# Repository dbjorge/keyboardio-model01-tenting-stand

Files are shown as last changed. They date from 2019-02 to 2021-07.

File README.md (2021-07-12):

# keyboardio-model01-tenting-stand

The 3D model for the tenting stand I use with my [Keyboardio Model 01](https://keyboard.io) keyboard.

**WARNING: To avoid wear on your keyboard, you MUST use some sort of pad/bumper between the stand/keyboard and your desk!** Using these models, part of the weight of the keyboard rests on one of its wooden edges; this is by design, as it forces a consistent angle between the stand and keyboard. However, you risk chipping the contact point on the keyboard unless you put some sort of padding there! I found that some felt stick-on furniture pads I had lying around worked well for this (I'm using [these SoftTouch brand ones](https://www.amazon.com/dp/B000SL4GEM/ref=cm_sw_em_r_mt_dp_U_9tJCCbQ0N5YCF)).

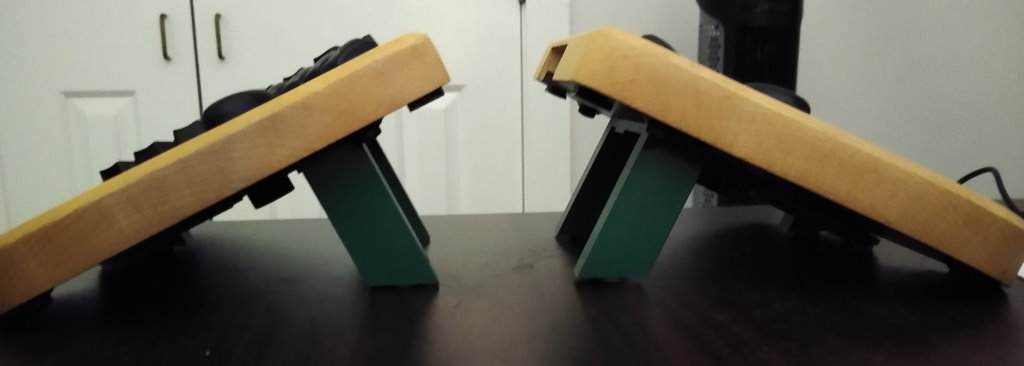
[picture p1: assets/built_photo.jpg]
Photo of printed stands assembled with a Model 01 keyboard


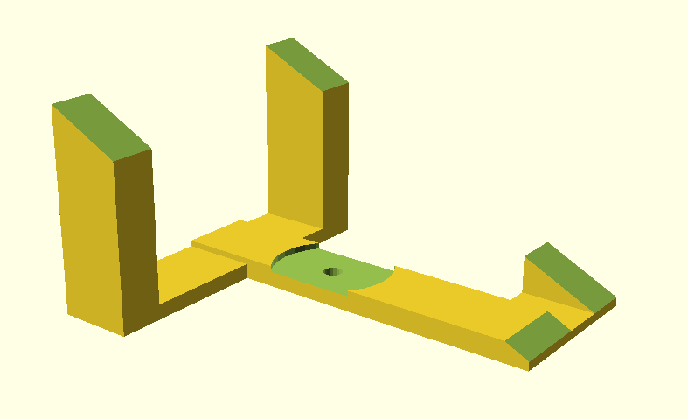
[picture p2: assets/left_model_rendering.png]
CAD rendering of left stand


## Usage

Unlike the original models this was based on, mine is not vertically symmetrical, so you must produce 2 different (mirrored) models to print the left and right stands. Use the `build_for_left_keyboard_half` variable at the top of the model source to switch which half you're rendering a model for.

You'll need to use [OpenSCAD](http://www.openscad.org/) to generate files usable by your printer from the source `model.scad` file.

You can use `build.ps1` to generate .stl files for the left and right halves to the `/out/` directory (it assumes you're using Windows with OpenSCAD installed to the default location).

I've printed the models in 1.75mm ABS on both a [FlashForge Creator Pro](http://www.flashforge.com/creator-pro-3d-printer/) and a [MakerBot Replicator 2X](https://pages.makerbot.com/ap-replicator-2x.html). I used 30% hexagonal infill and it feels stable (you might be able to get away with less, but I haven't tested it).

Some of the weight of the keyboard rests on an edge of the wood housing. You must use some sort of pad/bumper there to avoid damaging the wood over time.

## Licensing

Source licensed under MIT, resulting models licensed under [CC-BY 3.0](https://creativecommons.org/licenses/by/3.0/).

Based on [CC-BY 3.0](https://creativecommons.org/licenses/by/3.0/) [original](https://www.thingiverse.com/thing:2803754) [designs](https://www.thingiverse.com/thing:3047870) by Thingiverse users [fluffy](https://www.thingiverse.com/fluffy/about) and [deivid__](https://www.thingiverse.com/deivid__/about).

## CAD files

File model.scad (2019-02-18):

// "lengths" are x, "widths" are y, "heights" are z
// orientations assume looking along Z axis from pos to neg, with y axis at bottom, ie
// "left" is positive-y, "right" is negative-y, "upper" is positive-x, "lower" is negative-x

build_for_left_keyboard_half = 1; // 0 or 1, mirrors model

// for flashforge creator x, keep this <=130-140
total_length=130;

// How high to tent the middle, in millimeters
tent_height=64;
tent_angle=atan2(tent_height, total_length);
// Alternately, the angle to tent at, in degrees
//tent_angle=45;

// How wide to make the baseplates
base_center_bar_width=25; // [10:40] 
base_center_bar_height=7; // must be >5 for the screw to properly tighten

thumbscrew_offset_length=79;

// How far apart to spread the 'wings'
// right is negative direction, left is positive
tower_offset_left=30; // [0:100]
tower_offset_right=55;

tower_width=15; // [10:30]
tower_length=25;
tower_height=200;

// for flashforge creator x, keep this <= 110 or so
total_width=tower_offset_left + base_center_bar_width + tower_offset_right;

mirror([0,build_for_left_keyboard_half,0])
difference() {
    union() {
        // base center bar (where thumbscrew goes)
        cube([
            total_length,
            base_center_bar_width,
            base_center_bar_height]);
        
        // upper tower base plate
        translate([
            total_length - tower_length,
            -tower_offset_right,
            0])
        cube([
            tower_length,
            total_width,
            5]);
        
        // upper-left tower
        translate([
            total_length - tower_length,
            tower_offset_left + base_center_bar_width - tower_width,
            0])
        cube([
            tower_length,
            tower_width,
            tower_height]);
            
        // upper-right tower
        translate([
            total_length - tower_length,
            -tower_offset_right,
            0])
        cube([
            tower_length,
            tower_width,
            tower_height]);

        // lower tower base plate
        translate([
            25 - tower_length,
            0, // -tower_offset_right to include lower-right tower
            0])
        cube([
            tower_length,
            tower_offset_left + base_center_bar_width,
            3]);

        // lower-left tower
        translate([
            25 - tower_length,
            tower_offset_left + base_center_bar_width - tower_width,
            0])
        cube([
            tower_length,
            tower_width,
            tower_height]);
            
        // lower-right tower
        // We omit this because the keyboard has a foot in the same spot that serves this purpose instead
        /*
        translate([
            25 - tower_length,
            -tower_offset_right,
            0])
        cube([
            tower_length,
            tower_width,
            tower_height]);
        */

    }
    
    // thumbscrew gap
    translate([
        thumbscrew_offset_length,
        base_center_bar_width/2,
        5])
    cylinder(r1=20,r2=20,h=25);

    // mounting screwhole
    translate([
        thumbscrew_offset_length,
        base_center_bar_width/2,
        -1])
    cylinder(r=3.2,h=20,$fn=20);
    
    // top wedge
    translate([
        0,
        -tower_offset_right - 1,
        3])
    rotate([0,-tent_angle,0])
    cube([
        total_length * 2,
        total_width + 2,
        500]);
}

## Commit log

2019-02-17 version 1 of model
    [model.scad]
2019-02-17 verison 2 of model, updated to remove unnecessary extra leg and make better balanced at back
    [model.scad]
2019-02-17 verison 3 of model, updated to fix slight wobble in upper legs
    [model.scad]
2019-02-17 make upper support bar look less janky
    [model.scad]
2019-02-18 Remove upper support bar; it hurts more than it helps because it fixes any warping during print into place
    [model.scad, model01_left.stl, model01_right.stl]
2019-02-24 Add build script to generate .stl files on demand
    [model01_left.stl, model01_right.stl]
